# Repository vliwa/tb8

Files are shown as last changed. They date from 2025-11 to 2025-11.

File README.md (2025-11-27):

# tb8
## 8 bit Transport Buffer Processor
Modified transport triggered architecture using an intermediate buffer in the control unit.  

Implementing the intermediate buffer allows for 6 bits of the 8 bit instruction word to be used for transport
addressing, with 2 bits reserved for the opcode.  
## Logisim Implementation
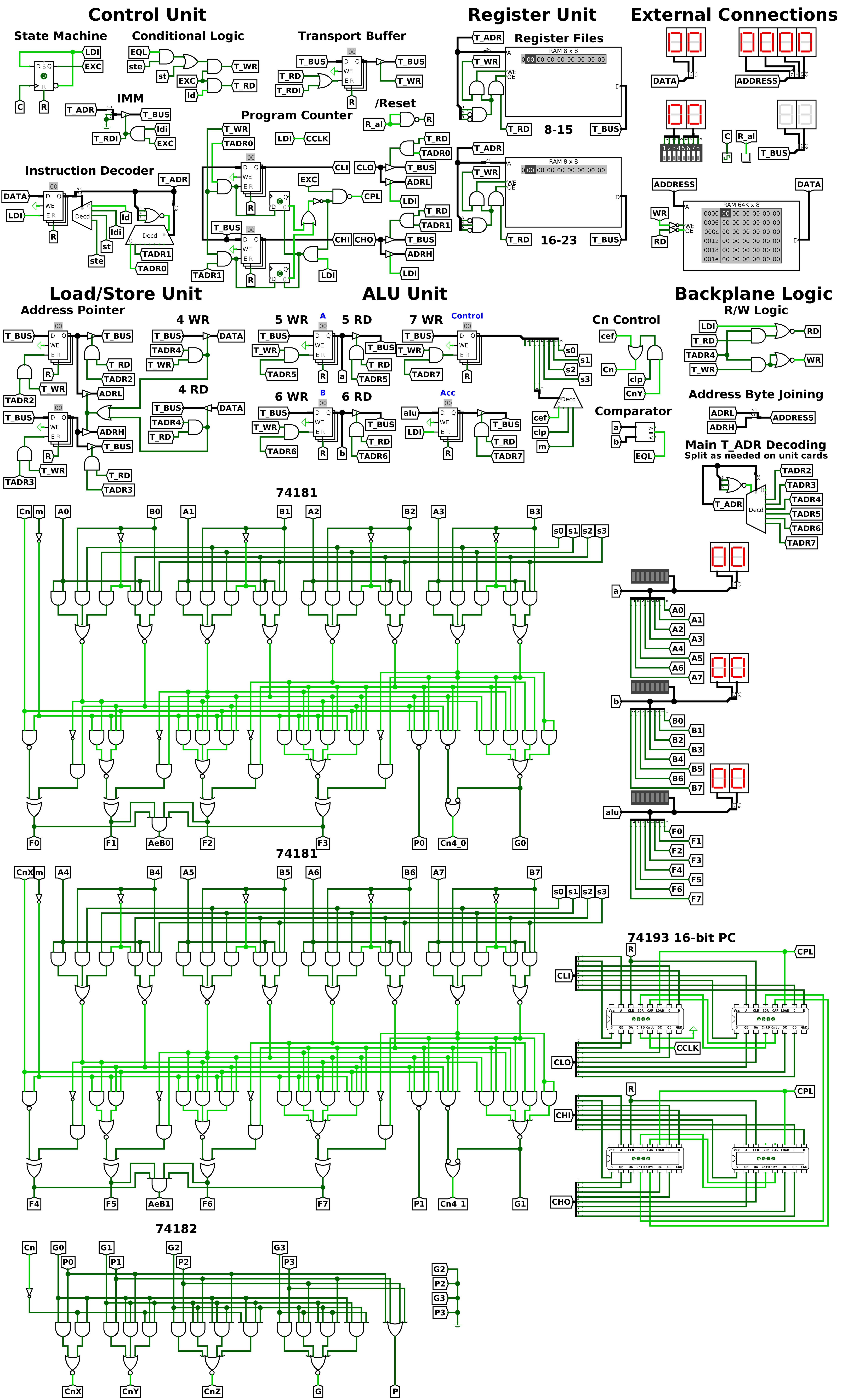
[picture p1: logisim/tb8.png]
Logisim Implementation


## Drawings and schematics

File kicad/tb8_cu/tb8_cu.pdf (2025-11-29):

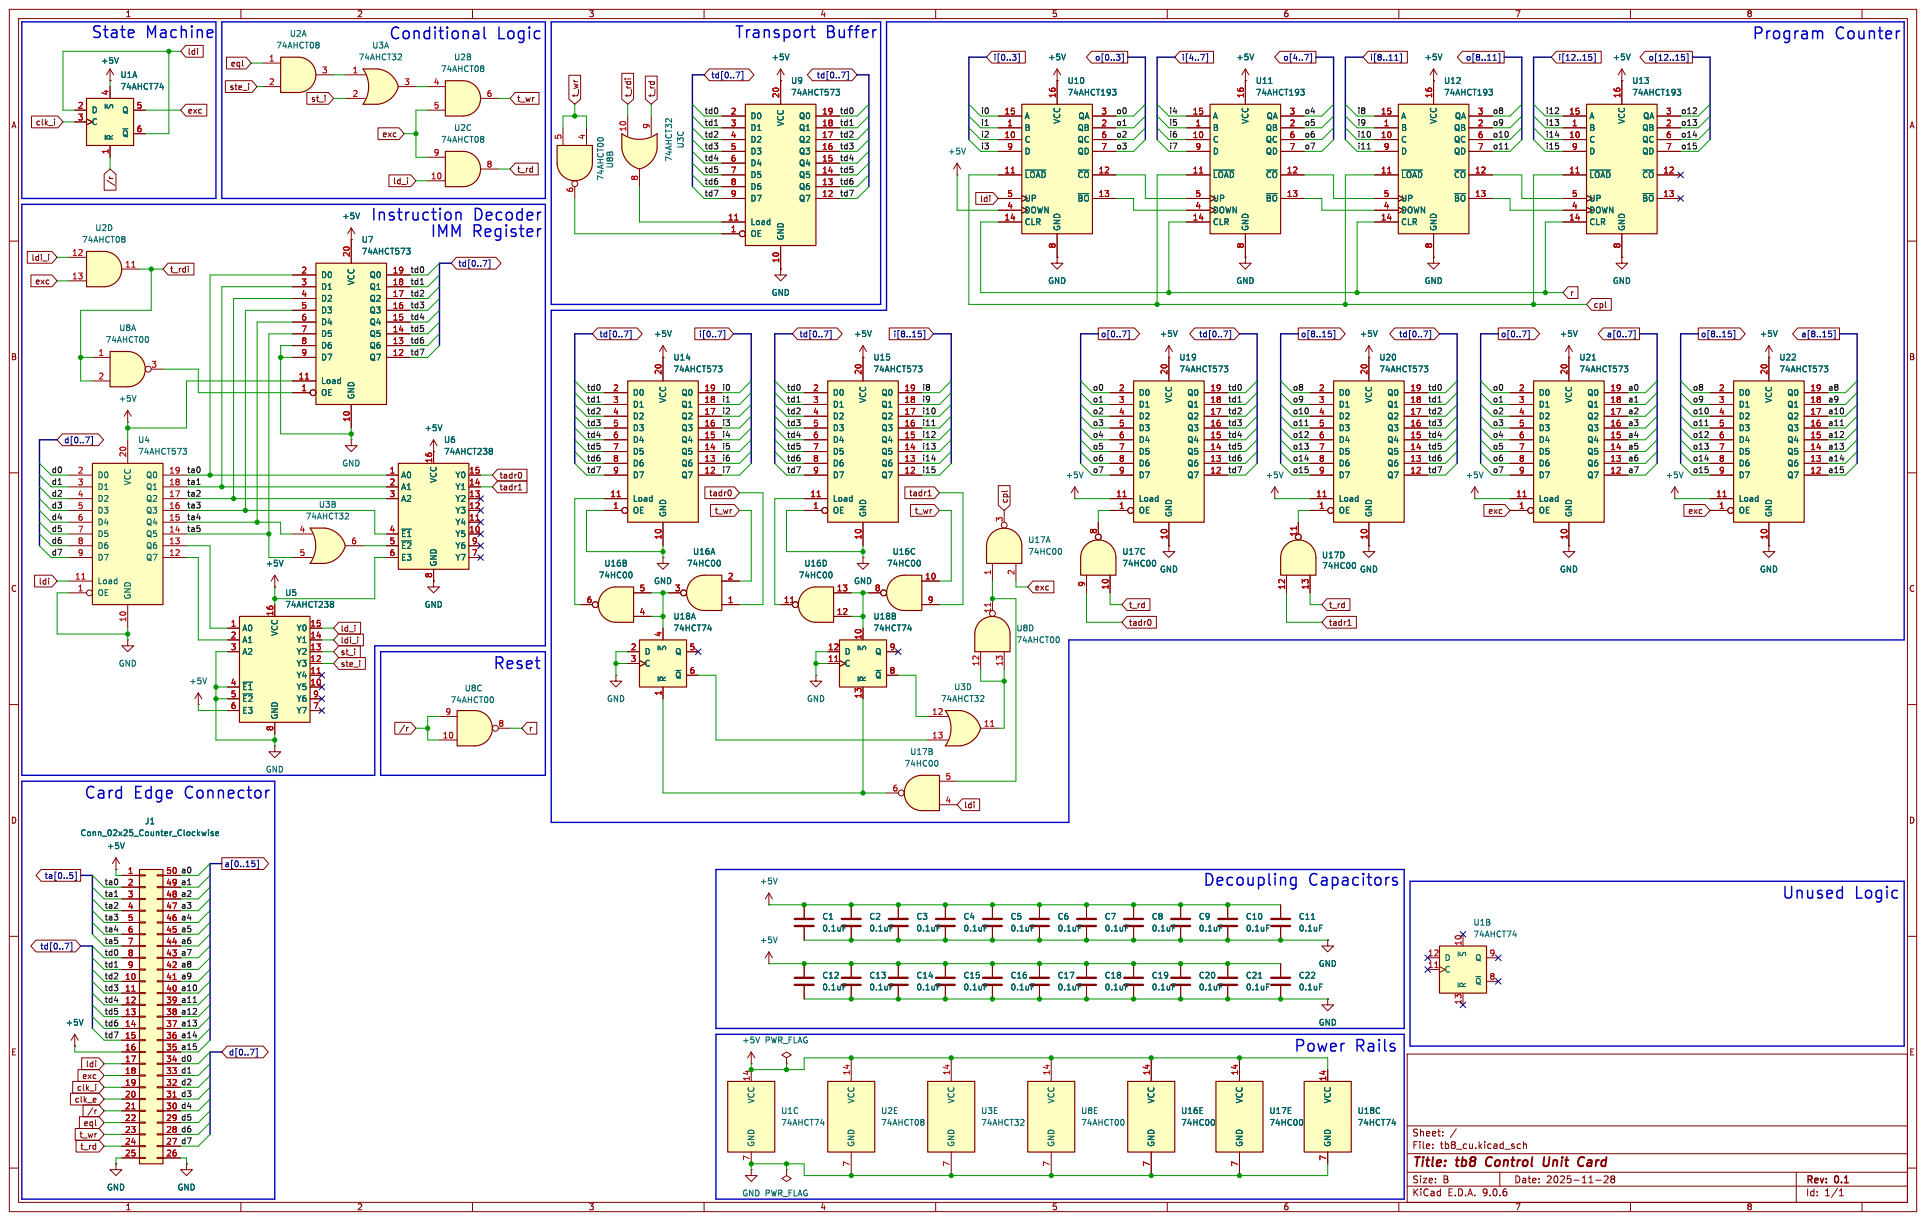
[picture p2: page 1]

74AHCT193

74AHCT193 A

Id: 1/1 Title: tb8 Control Unit Card

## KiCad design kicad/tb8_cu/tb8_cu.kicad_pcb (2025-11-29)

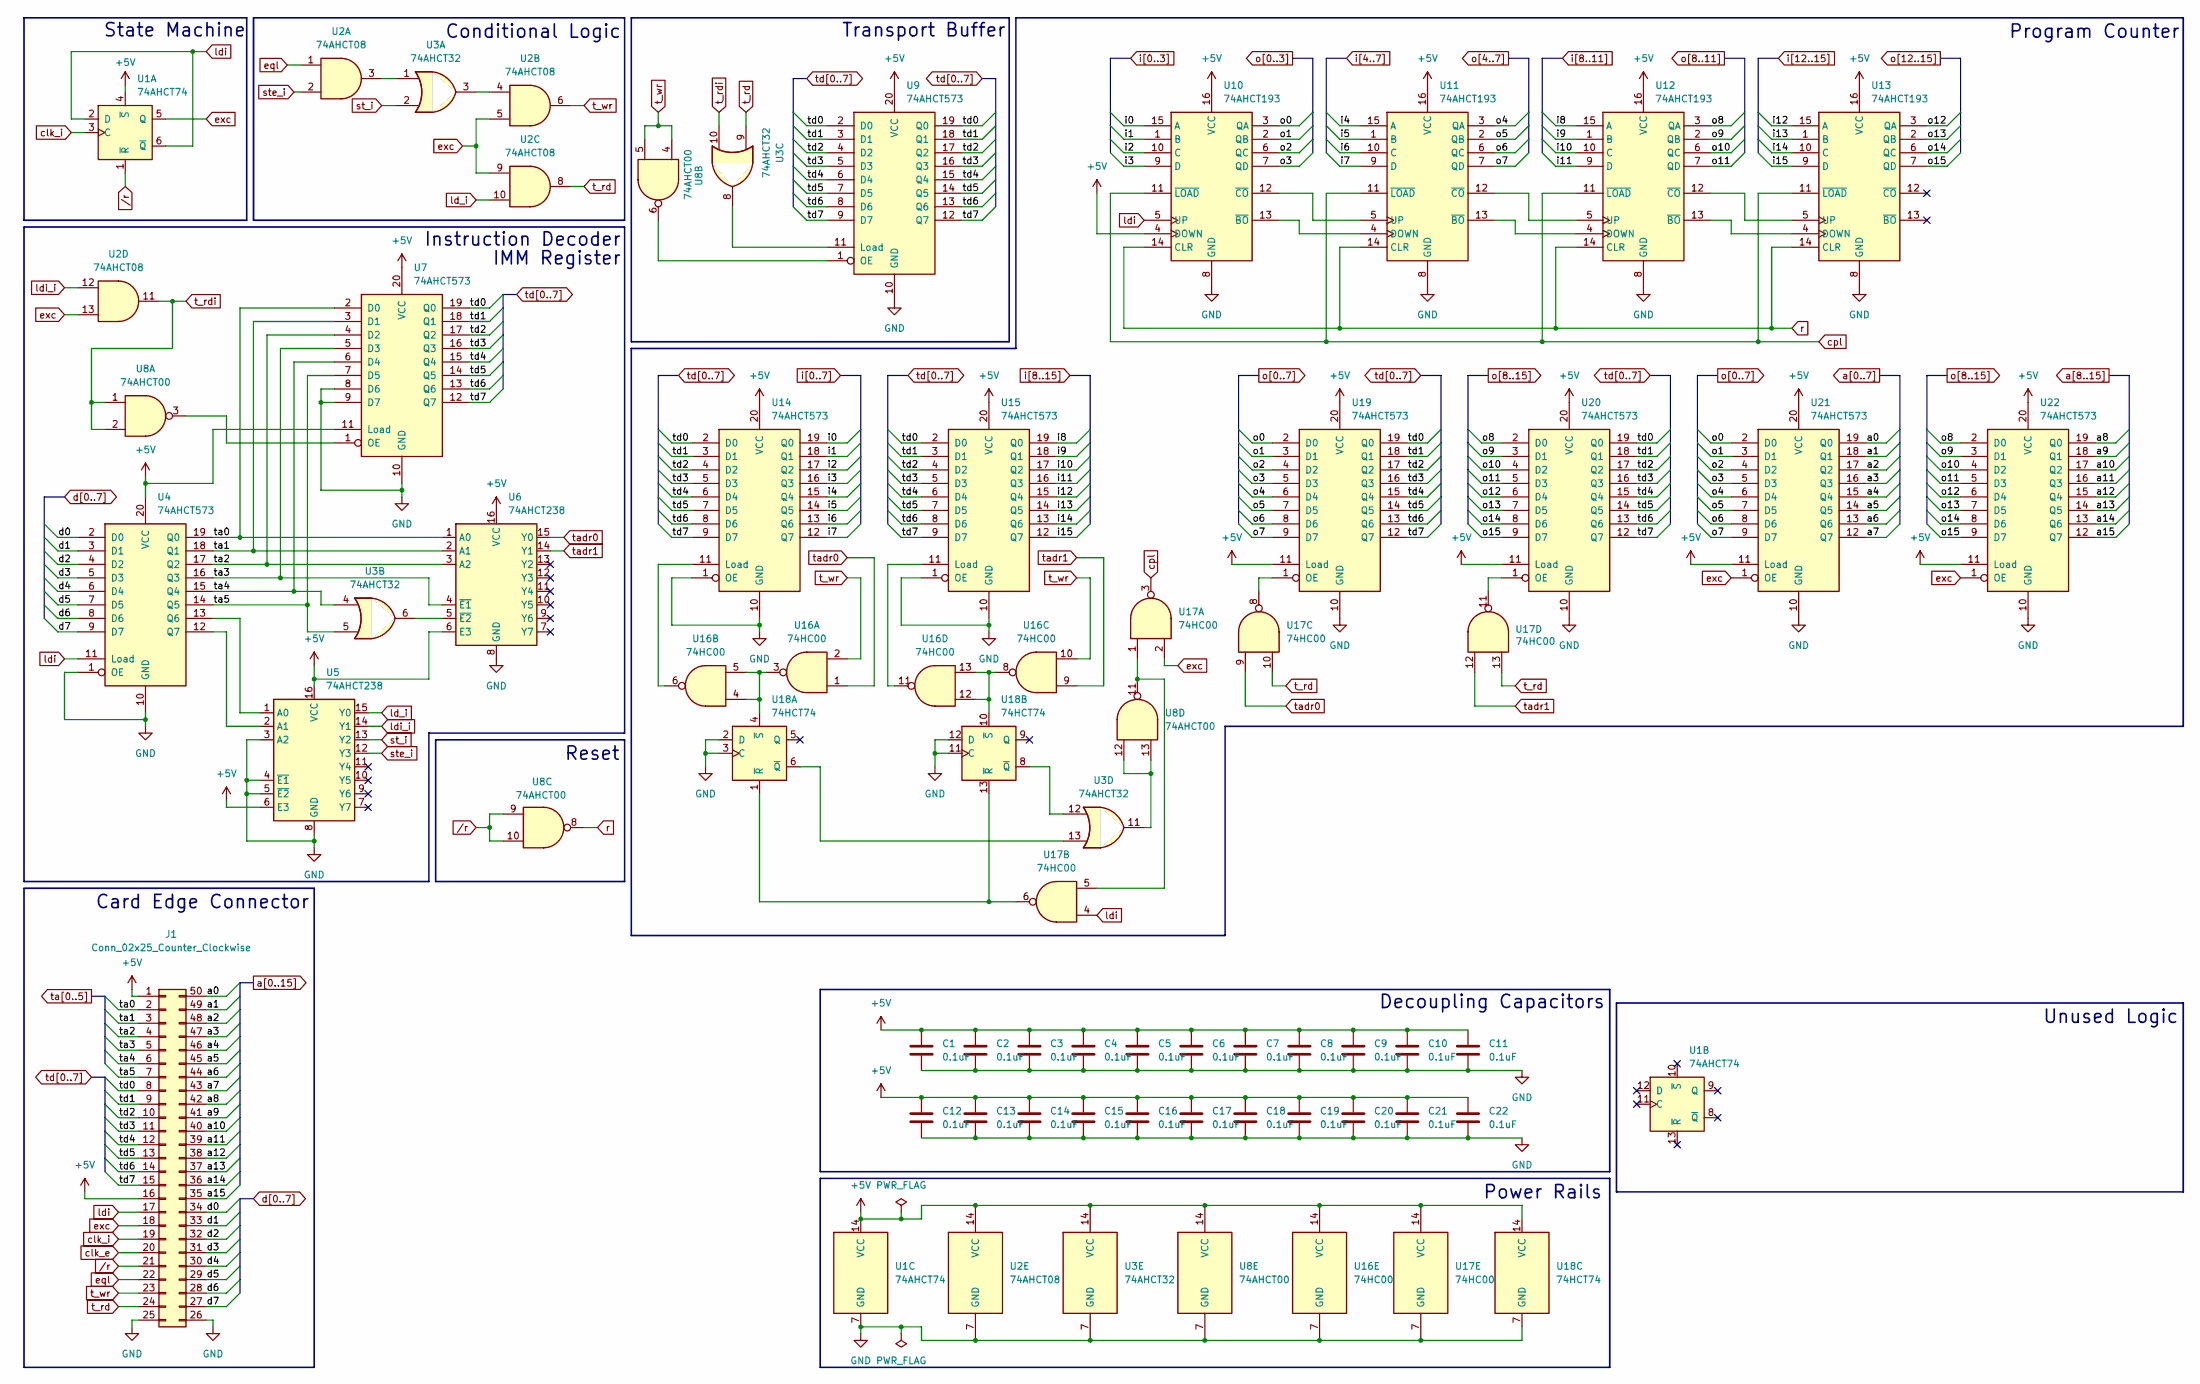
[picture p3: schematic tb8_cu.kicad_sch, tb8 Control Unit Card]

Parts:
C1, C2, C3, C4, C5, C6, C7, C8, C9, C10, C11, C12, C13, C14, C15, C16, C17, C18, C19, C20, C21, C22: 0.1uF; C_Rect_L4.0mm_W2.5mm_P2.50mm
J1: Conn_02x25_Counter_Clockwise; 25_2.54spacing
U1: 74AHCT74; DIP-14_W7.62mm_Socket_LongPads
U2: 74AHCT08; DIP-14_W7.62mm_Socket_LongPads
U3: 74AHCT32; DIP-14_W7.62mm_Socket_LongPads
U4, U7, U9, U14, U15, U19, U20, U21, U22: 74AHCT573; DIP-20_W7.62mm_Socket_LongPads
U5, U6: 74AHCT238; DIP-16_W7.62mm_Socket_LongPads
U8: 74AHCT00; DIP-14_W7.62mm_Socket_LongPads
U10, U11, U12, U13: 74AHCT193; DIP-16_W7.62mm_Socket_LongPads
U16, U17: 74HC00; DIP-14_W7.62mm_Socket_LongPads
U18: 74HCT74; DIP-14_W7.62mm_Socket_LongPads

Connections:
+5V: C1.1, C2.1, C3.1, C4.1, C5.1, C6.1, C7.1, C8.1, C9.1, C10.1, C11.1, C12.1, C13.1, C14.1, C15.1, C16.1, C17.1, C18.1, C19.1, C20.1, C21.1, C22.1, J1.1, J1.16, U1.4 (~S), U1.14 (VCC), U2.14 (VCC), U3.14 (VCC), U4.20 (VCC), U5.6 (E3), U5.16 (VCC), U6.6 (E3), U6.16 (VCC), U7.11 (Load), U7.20 (VCC), U8.14 (VCC), U9.20 (VCC), U10.4 (DOWN), U10.16 (VCC), U11.16 (VCC), U12.16 (VCC), U13.16 (VCC), U14.20 (VCC), U15.20 (VCC), U16.14 (VCC), U17.14 (VCC), U18.14 (VCC), U19.11 (Load), U19.20 (VCC), U20.11 (Load), U20.20 (VCC), U21.11 (Load), U21.20 (VCC), U22.11 (Load), U22.20 (VCC)
GND: C1.2, C2.2, C3.2, C4.2, C5.2, C6.2, C7.2, C8.2, C9.2, C10.2, C11.2, C12.2, C13.2, C14.2, C15.2, C16.2, C17.2, C18.2, C19.2, C20.2, C21.2, C22.2, J1.25, J1.26, U1.7 (GND), U2.7 (GND), U3.7 (GND), U4.1 (OE), U4.10 (GND), U5.3 (A2), U5.4 (~E1), U5.5 (~E2), U5.8 (GND), U6.8 (GND), U7.8 (D6), U7.9 (D7), U7.10 (GND), U8.7 (GND), U9.10 (GND), U10.8 (GND), U11.8 (GND), U12.8 (GND), U13.8 (GND), U14.1 (OE), U14.10 (GND), U15.1 (OE), U15.10 (GND), U16.7 (GND), U17.7 (GND), U18.2 (D), U18.3 (C), U18.7 (GND), U18.11 (C), U18.12 (D), U19.10 (GND), U20.10 (GND), U21.10 (GND), U22.10 (GND)
unnamed: U2.3, U3.1
unnamed: U2.4, U3.3
unnamed: U3.11, U8.12, U8.13
unnamed: U4.13 (Q6), U5.1 (A0)
unnamed: U4.12 (Q7), U5.2 (A1)
unnamed: U3.6, U6.5 (~E2)
unnamed: U7.1 (OE), U8.3
unnamed: U3.8, U9.11 (Load)
unnamed: U8.6, U9.1 (OE)
unnamed: U10.13 (~BO), U11.4 (DOWN)
unnamed: U10.12 (~CO), U11.5 (UP)
unnamed: U11.13 (~BO), U12.4 (DOWN)
unnamed: U11.12 (~CO), U12.5 (UP)
unnamed: U12.13 (~BO), U13.4 (DOWN)
unnamed: U12.12 (~CO), U13.5 (UP)
unnamed: U14.11 (Load), U16.6
unnamed: U15.11 (Load), U16.11
unnamed: U8.11, U17.1, U17.5
unnamed: U3.13, U18.6 (~Q)
unnamed: U17.6, U18.1 (~R), U18.13 (~R)
unnamed: U16.3, U16.4, U16.5, U18.4 (~S)
unnamed: U3.12, U18.8 (~Q)
unnamed: U16.8, U16.12, U16.13, U18.10 (~S)
unnamed: U17.8, U19.1 (OE)
unnamed: U17.11, U20.1 (OE)
a0: J1.50, U21.19 (Q0)
a1: J1.49, U21.18 (Q1)
a2: J1.48, U21.17 (Q2)
a3: J1.47, U21.16 (Q3)
a4: J1.46, U21.15 (Q4)
a5: J1.45, U21.14 (Q5)
a6: J1.44, U21.13 (Q6)
a7: J1.43, U21.12 (Q7)
a8: J1.42, U22.19 (Q0)
a9: J1.41, U22.18 (Q1)
a10: J1.40, U22.17 (Q2)
a11: J1.39, U22.16 (Q3)
a12: J1.38, U22.15 (Q4)
a13: J1.37, U22.14 (Q5)
a14: J1.36, U22.13 (Q6)
a15: J1.35, U22.12 (Q7)
clk_e: J1.20
clk_i: J1.19, U1.3 (C)
cpl: U10.11 (~LOAD), U11.11 (~LOAD), U12.11 (~LOAD), U13.11 (~LOAD), U17.3
d0: J1.34, U4.2 (D0)
d1: J1.33, U4.3 (D1)
d2: J1.32, U4.4 (D2)
d3: J1.31, U4.5 (D3)
d4: J1.30, U4.6 (D4)
d5: J1.29, U4.7 (D5)
d6: J1.28, U4.8 (D6)
d7: J1.27, U4.9 (D7)
eql: J1.22, U2.1
exc: J1.18, U1.5 (Q), U2.5, U2.9, U2.13, U17.2, U21.1 (OE), U22.1 (OE)
i0: U10.15 (A), U14.19 (Q0)
i1: U10.1 (B), U14.18 (Q1)
i2: U10.10 (C), U14.17 (Q2)
i3: U10.9 (D), U14.16 (Q3)
i4: U11.15 (A), U14.15 (Q4)
i5: U11.1 (B), U14.14 (Q5)
i6: U11.10 (C), U14.13 (Q6)
i7: U11.9 (D), U14.12 (Q7)
i8: U12.15 (A), U15.19 (Q0)
i9: U12.1 (B), U15.18 (Q1)
i10: U12.10 (C), U15.17 (Q2)
i11: U12.9 (D), U15.16 (Q3)
i12: U13.15 (A), U15.15 (Q4)
i13: U13.1 (B), U15.14 (Q5)
i14: U13.10 (C), U15.13 (Q6)
i15: U13.9 (D), U15.12 (Q7)
ld_i: U2.10, U5.15 (Y0)
ldi: J1.17, U1.2 (D), U1.6 (~Q), U4.11 (Load), U10.5 (UP), U17.4
ldi_i: U2.12, U5.14 (Y1)
o0: U10.3 (QA), U19.2 (D0), U21.2 (D0)
o1: U10.2 (QB), U19.3 (D1), U21.3 (D1)
o2: U10.6 (QC), U19.4 (D2), U21.4 (D2)
o3: U10.7 (QD), U19.5 (D3), U21.5 (D3)
o4: U11.3 (QA), U19.6 (D4), U21.6 (D4)
o5: U11.2 (QB), U19.7 (D5), U21.7 (D5)
o6: U11.6 (QC), U19.8 (D6), U21.8 (D6)
o7: U11.7 (QD), U19.9 (D7), U21.9 (D7)
o8: U12.3 (QA), U20.2 (D0), U22.2 (D0)
o9: U12.2 (QB), U20.3 (D1), U22.3 (D1)
o10: U12.6 (QC), U20.4 (D2), U22.4 (D2)
o11: U12.7 (QD), U20.5 (D3), U22.5 (D3)
o12: U13.3 (QA), U20.6 (D4), U22.6 (D4)
o13: U13.2 (QB), U20.7 (D5), U22.7 (D5)
o14: U13.6 (QC), U20.8 (D6), U22.8 (D6)
o15: U13.7 (QD), U20.9 (D7), U22.9 (D7)
r: U8.8, U10.14 (CLR), U11.14 (CLR), U12.14 (CLR), U13.14 (CLR)
st_i: U3.2, U5.13 (Y2)
ste_i: U2.2, U5.12 (Y3)
t_rd: J1.24, U2.8, U3.9, U17.10, U17.13
t_rdi: U2.11, U3.10, U8.1, U8.2
t_wr: J1.23, U2.6, U8.4, U8.5, U16.2, U16.10
ta0: J1.2, U4.19 (Q0), U6.1 (A0), U7.2 (D0)
ta1: J1.3, U4.18 (Q1), U6.2 (A1), U7.3 (D1)
ta2: J1.4, U4.17 (Q2), U6.3 (A2), U7.4 (D2)
ta3: J1.5, U4.16 (Q3), U6.4 (~E1), U7.5 (D3)
ta4: J1.6, U3.4, U4.15 (Q4), U7.6 (D4)
ta5: J1.7, U3.5, U4.14 (Q5), U7.7 (D5)
tadr0: U6.15 (Y0), U16.1, U17.9
tadr1: U6.14 (Y1), U16.9, U17.12
td0: J1.8, U7.19 (Q0), U9.2 (D0), U9.19 (Q0), U14.2 (D0), U15.2 (D0), U19.19 (Q0), U20.19 (Q0)
td1: J1.9, U7.18 (Q1), U9.3 (D1), U9.18 (Q1), U14.3 (D1), U15.3 (D1), U19.18 (Q1), U20.18 (Q1)
td2: J1.10, U7.17 (Q2), U9.4 (D2), U9.17 (Q2), U14.4 (D2), U15.4 (D2), U19.17 (Q2), U20.17 (Q2)
td3: J1.11, U7.16 (Q3), U9.5 (D3), U9.16 (Q3), U14.5 (D3), U15.5 (D3), U19.16 (Q3), U20.16 (Q3)
td4: J1.12, U7.15 (Q4), U9.6 (D4), U9.15 (Q4), U14.6 (D4), U15.6 (D4), U19.15 (Q4), U20.15 (Q4)
td5: J1.13, U7.14 (Q5), U9.7 (D5), U9.14 (Q5), U14.7 (D5), U15.7 (D5), U19.14 (Q5), U20.14 (Q5)
td6: J1.14, U7.13 (Q6), U9.8 (D6), U9.13 (Q6), U14.8 (D6), U15.8 (D6), U19.13 (Q6), U20.13 (Q6)
td7: J1.15, U7.12 (Q7), U9.9 (D7), U9.12 (Q7), U14.9 (D7), U15.9 (D7), U19.12 (Q7), U20.12 (Q7)
/r: J1.21, U1.1 (~R), U8.9, U8.10

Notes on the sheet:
Unused Logic
Program Counter
Reset
State Machine
Instruction Decoder
Power Rails
Transport Buffer
Card Edge Connector
Conditional Logic
Decoupling Capacitors
IMM Register

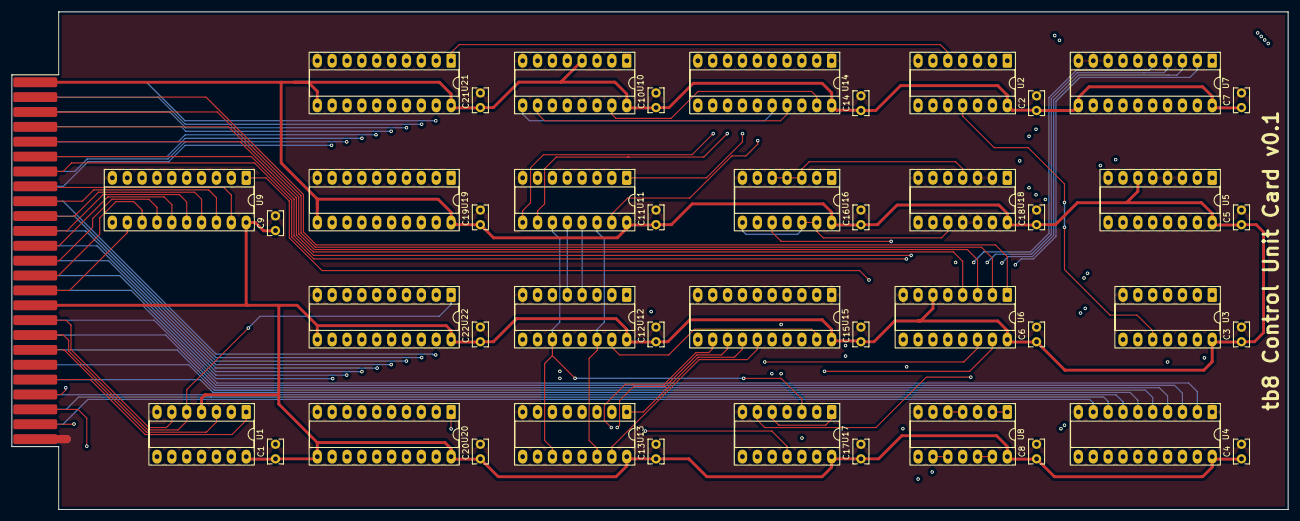
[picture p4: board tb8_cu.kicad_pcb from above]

Board: 4 copper layers, 218.0 x 85.0 mm, 45 parts (0 on the bottom side), 113 nets.

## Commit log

2025-11-28 initial tb8_cu kicad
    [tb8_cu.kicad_pcb, tb8_cu.kicad_sch]
2025-11-28 tb8_cu sch&pcb in progress
    [tb8_cu.kicad_pcb, tb8_cu.kicad_sch]
2025-11-29 tb8_cu first revision sch&pcb done
    [tb8_cu.kicad_pcb]
2025-11-29 tba_cu sch pdf
    [tb8_cu.kicad_sch]
2025-11-29 tb8_cu pcb routing cleanup
    [tb8_cu.kicad_pcb]
2025-11-29 EBC25DCWN footprint
    [tb8_cu.kicad_pcb, tb8_cu.kicad_sch]
2025-11-29 tb8_cu remove card edge silkscreen
    [tb8_cu.kicad_pcb]
